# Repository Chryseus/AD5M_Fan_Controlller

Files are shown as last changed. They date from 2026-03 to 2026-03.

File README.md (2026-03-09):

# AD5M Fan Controlller

This is a work in progress fan controller for the Flashforge AD5M / AD5X 3d printer that provides remote fan control over Wifi as well as chamber monitoring.

## Hardware

This is designed for the ESP32 C3 Super Mini but will work with any arduino compatible device that supports Wifi.

BME280 is used for temperature, pressure and humidity sensing.

ENS160 is used for air quality sensing.

Any PWM driver will work for the fans, I've used DRV8871.

Recirculation fan is a 5015 blower, 24V 8500 RPM max.

Exhaust fan is a 4020 24V.

Power is drawn from the built in 24V supply and regulated down to 5V for the ESP32 using a LMR14006Y buck converter (you could use a 7805 instead), the ESP32 3.3V regulator is used to power the sensors.

## 3D Printed Parts

For the recirculation duct [this](https://www.printables.com/model/1243577-flashforge-adventurer-5m-recirculating-air-duct-50) is used for the AD5M, for AD5X users [this](https://www.printables.com/model/1473971-ad5x-internal-circulation-air-filtration-duct-with) or [this](https://www.printables.com/model/1472826-ad5x-recirculation-duct-blower-5015) may work.

For the exhaust duct I have used [this](https://www.printables.com/model/1375541-adventurer-5m-venting-kit-for-the-non-pro-version).

### Roadmap

- [x] Manual fan control

- [x] Sensor display

- [x] Schematic

- [ ] 3D printed mounting parts

- [ ] Automatic mode based on sensor data

**Possible future additions**

- [ ] Data logging / plotting

- [ ] Send data to external server

- [ ] 3D printer communication

- [x] Custom PCB

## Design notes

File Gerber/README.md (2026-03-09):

Intended for JLCPCB

Layers: 2

Material: FR-4

Board Size: 50 x 55mm

Copper: 1oz

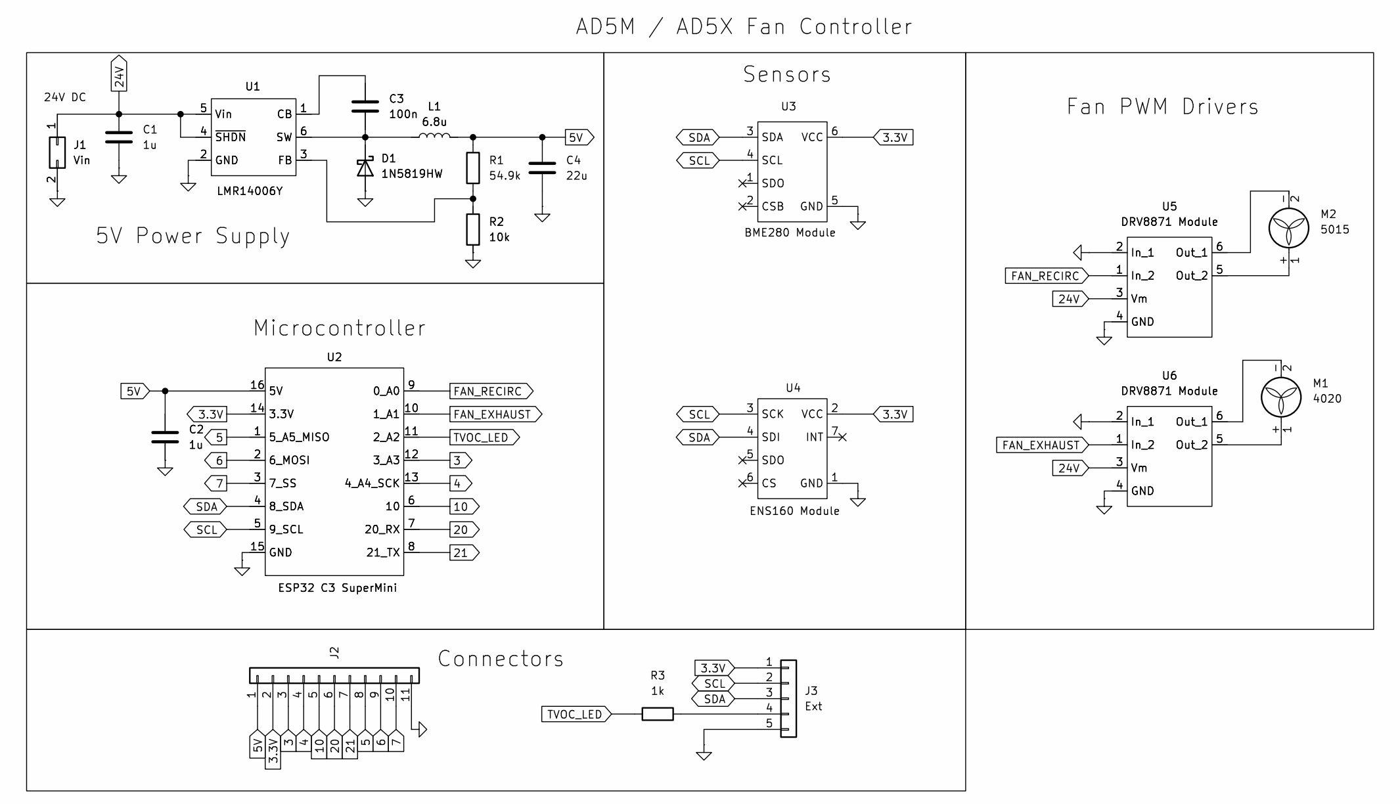
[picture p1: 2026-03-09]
Schematic.png

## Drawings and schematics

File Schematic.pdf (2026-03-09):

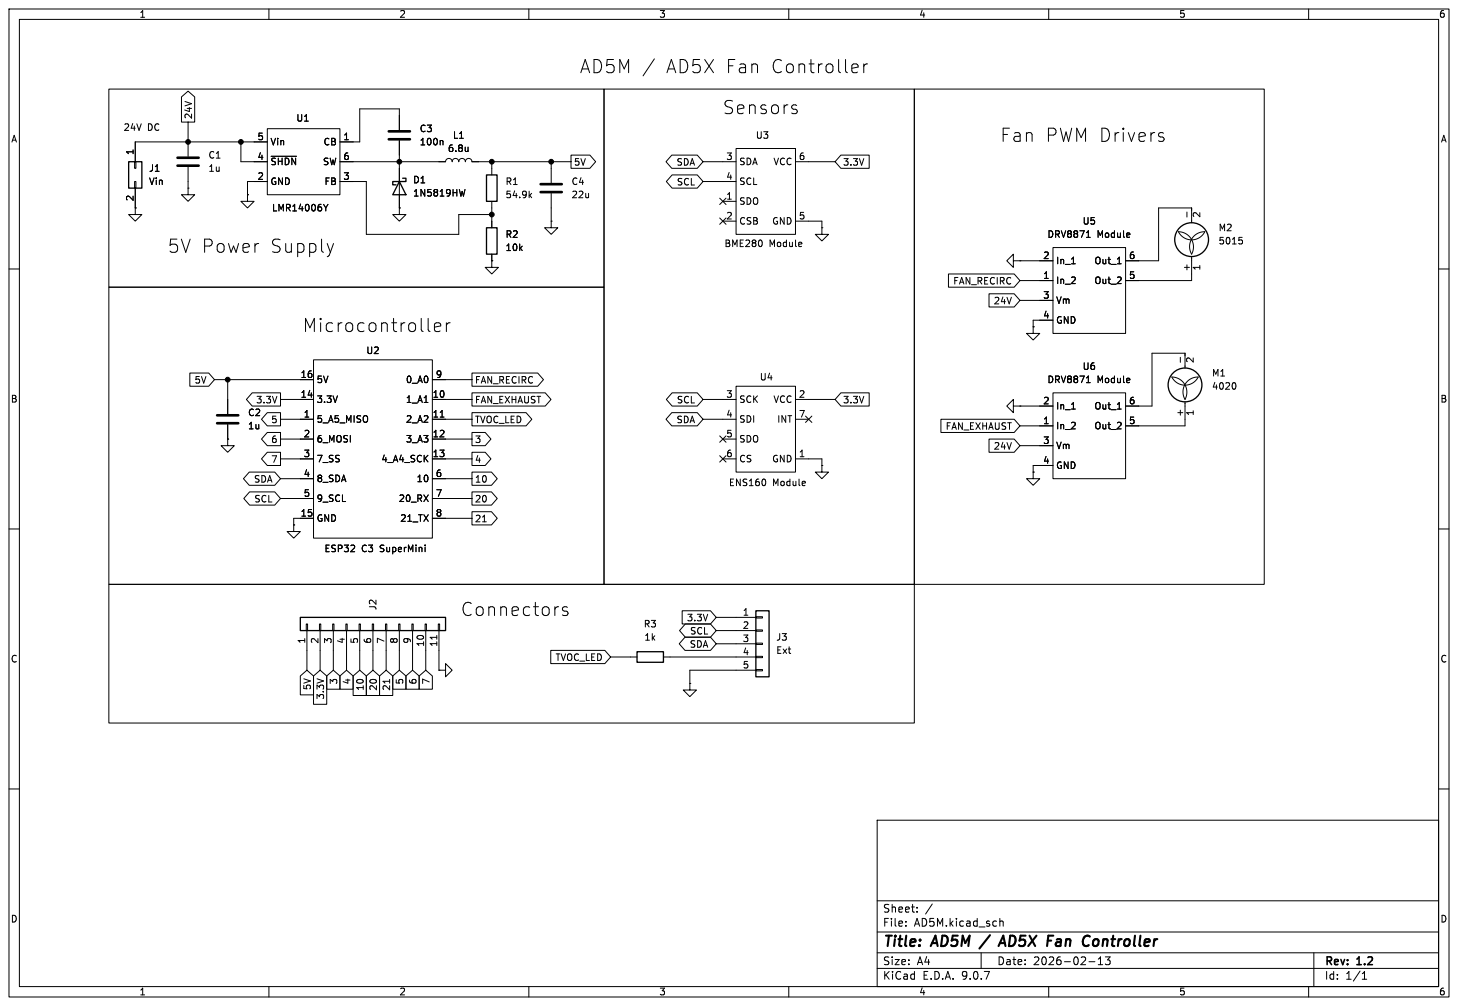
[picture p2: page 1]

Id: 1/1 Title: AD5M / AD5X Fan Controller File: AD5M.kicad_sch Sheet: /

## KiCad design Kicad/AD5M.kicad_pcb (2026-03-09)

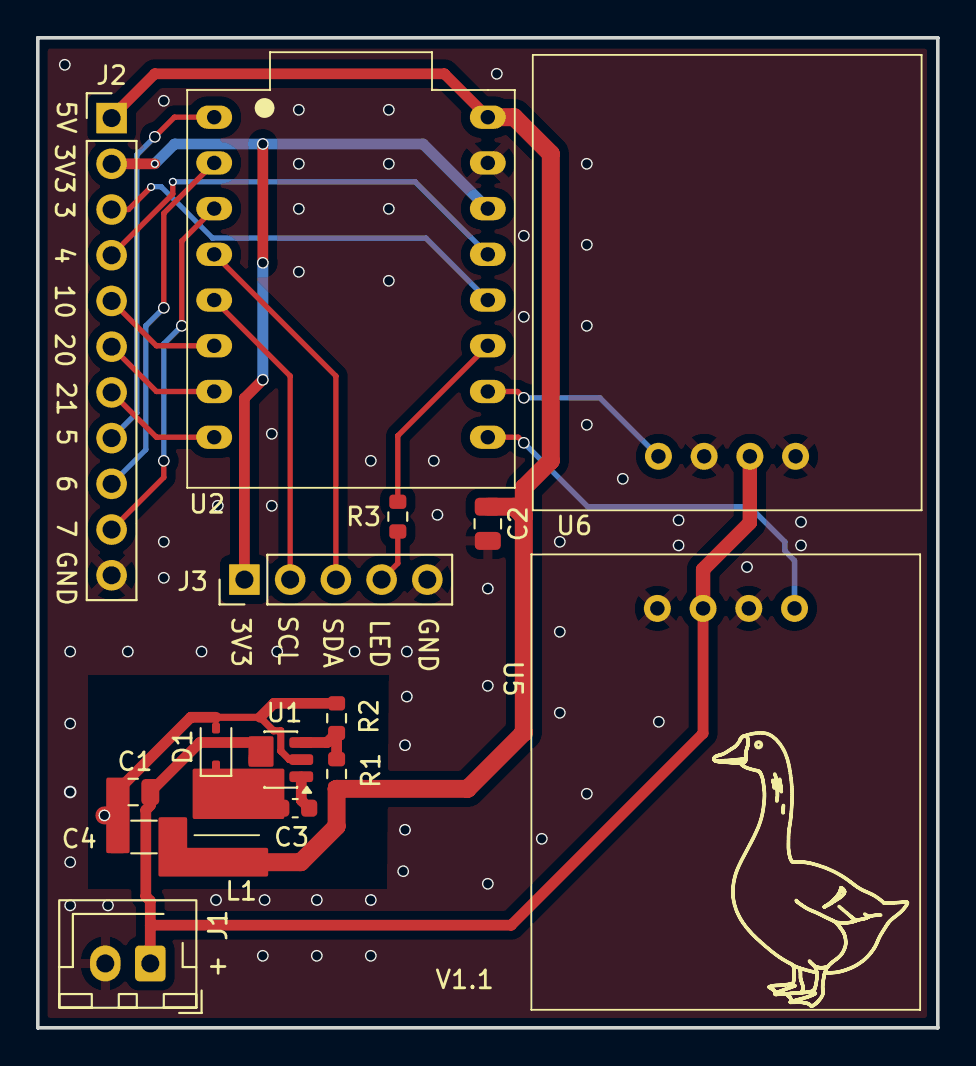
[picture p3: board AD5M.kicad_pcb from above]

Board: 2 copper layers, 50.0 x 55.0 mm, 16 parts (0 on the bottom side), 21 nets.

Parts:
C1, C2: 1u; C_0805_2012Metric
C3: 100n; C_0603_1608Metric
C4: 22u; C_1206_3216Metric
D1: 1N5819HW; D_SOD-323
J1: Vin; JST_XH_B2B-XH-AM_1x02_P2.50mm_Vertical
J2: Conn_01x11; PinHeader_1x11_P2.54mm_Vertical
J3: Ext; PinHeader_1x05_P2.54mm_Vertical
L1: 6.8u; SMNR4030
R1: 54.9k; R_0603_1608Metric
R2: 10k; R_0603_1608Metric
R3: 1k; R_0603_1608Metric
U1: LMR14006Y; TSOT-23-6
U2: ESP32 C3 SuperMini; ESP32_SuperMini_C3
U5, U6: DRV8871 Module

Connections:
3: J2.3, U2.12 (3_A3)
3.3V: J2.2, J3.1, U2.14 (3.3V)
4: J2.4, U2.13 (4_A4_SCK)
5: J2.8, U2.1 (5_A5_MISO)
5V: C2.1, C4.1, J2.1, L1.2, R1.1, U2.16 (5V)
6: J2.9, U2.2 (6_MOSI)
7: J2.10, U2.3 (7_SS)
10: J2.5, U2.6 (10)
20: J2.6, U2.7 (20_RX)
21: J2.7, U2.8 (21_TX)
24V: C1.1, J1.1, U1.4 (~SHDN), U1.5 (Vin), U5.3 (Vm), U6.3 (Vm)
FAN_EXHAUST: U2.10 (1_A1), U6.1 (In_2)
FAN_RECIRC: U2.9 (0_A0), U5.1 (In_2)
GND: C1.2, C2.2, C4.2, D1.2 (A), J1.2, J2.11, J3.5, R2.2, U1.2 (GND), U2.15 (GND), U5.2 (In_1), U5.4 (GND), U6.2 (In_1), U6.4 (GND)
unnamed: C3.2, D1.1 (K), L1.1, U1.6 (SW)
unnamed: J3.4, R3.1
unnamed: C3.1, U1.1 (CB)
unnamed: R1.2, R2.1, U1.3 (FB)
SCL: J3.2, U2.5 (9_SCL)
SDA: J3.3, U2.4 (8_SDA)
TVOC_LED: R3.2, U2.11 (2_A2)

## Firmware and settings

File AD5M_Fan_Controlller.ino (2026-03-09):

/**********************************
*** AD5M Ventilation Controller ***
*** For ESP32 SuperMini C3      ***
***********************************/

#include <WiFi.h> // Arduino WiFi Library
#include <BME280I2C.h> // BME280 Library (Tyler Glenn)
#include <ScioSense_ENS160.h> // ENS160 Adafruit library
#include <Wire.h>
#include <EEPROM.h>
#include "wifi_settings.h" // User WiFi settings

#define NETWORK_PORT 8080
const char* VERSION = "0.2"; // Firmware release version

/**** Pin Layout  ****/
// 8 - I2C SDA
// 9 - I2C SCL
// 0 - PWM Recirculation Fan
// 1 - PWM Exhaust Fan
// 2 - TVOC High LED
const int PIN_SDA = 8;
const int PIN_SCL = 9;
const int PIN_RECIRC = 0;
const int PIN_EXHAUST = 1;
const int PIN_TVOC = 2;

struct VC_Settings {
    int eeprom_saved;
    int mode; // 0 - auto, 1 - manual
    int fan_recirc_enable;
    int fan_exhaust_enable;
    int fan_recirc_pwm;
    int fan_exhaust_pwm;
};
int save_to_eeprom = 0;
VC_Settings vc_settings;
NetworkServer server(NETWORK_PORT);
unsigned long last_wifi_check = 0;
const unsigned long WIFI_CHECK_INTERVAL_MS = 30000;

// Fan Limits
const int fan_recirc_min = 55;
const int fan_exhaust_min = 50;
int fan_recirc_last = 0;
int fan_exhaust_last = 0;


// BME280 Temperature / Humidity / Pressure sensor
bool bme280_detected = false;
bool bmp280_detected = false;
BME280I2C::Settings settings (
    BME280::OSR_X1, //temp
    BME280::OSR_X1, //humid
    BME280::OSR_X4, // pressure
    BME280::Mode_Normal, // Mode
    BME280::StandbyTime_500us, // Standby time
    BME280::Filter_16, // Filter
    BME280::SpiEnable_False,
    BME280I2C::I2CAddr_0x76
);
BME280I2C bme(settings);
float temperature = 0.0; // C
float pressure = 0.0; // hPa
float humidity = 0.0; // RH %

// ENS160 VOC Sensor
bool ens160_detected = false;
ScioSense_ENS160 ens160(ENS160_I2CADDR_1); // Change if needed, 0 = 0x52, 1 = 0x53
int air_AQI = 0; // 1-5
int air_TVOC = 0; // ppb
int air_eCO2 = 0; // ppm

// HTML
String http_header = R"(HTTP/1.1 200 OK
Content-Type: text/html

<!DOCTYPE HTML>
<html>
<head>
	<title>AD5M Ventilation Controller</title>
	<style>
	body { padding: 0; margin: 0; font-family: segoe ui; font-size: 18px;}
	label { margin: 0px 10px; }
  span.safe { color: #1daf1d; }
  span.warn { color: #fdaa28; }
  span.danger { color: #ff1414; }
	#container {
		background-color: #f1f1f1;
		width: 1024px;
		margin: 0px auto;
		padding: 10px; }

	</style>
</head>
<body>
<div id="container">
<h1>AD5M Ventilation Controller</h1>
)";

String http_footer = R"(<br><a href="https://github.com/Chryseus/AD5M_Fan_Controlller">Github</a>
</div>
</body>
</html>

)";

void connect_wifi() {
  while (!WiFi.isConnected()) {
    Serial.print("Connecting to ");
    Serial.println(SSID);
    WiFi.begin(SSID, WPA_KEY);
    delay(10000);
  }

  Serial.println("Connected.");
  Serial.print("Local IP address: ");
  Serial.println(WiFi.localIP());
}

void check_eeprom() {
  EEPROM.get(0, vc_settings);

  if (vc_settings.eeprom_saved != 1)
  {
    Serial.println("Refreshing EEPROM.");
    vc_settings.mode = 0;
    vc_settings.fan_exhaust_enable = 0;
    vc_settings.fan_recirc_enable = 0;
    vc_settings.fan_exhaust_pwm = fan_exhaust_min;
    vc_settings.fan_recirc_pwm = fan_recirc_min;
    vc_settings.eeprom_saved = 1;
    EEPROM.put(0, vc_settings);
    EEPROM.commit();
  }
}

void check_wifi() {
  if (!WiFi.isConnected()) {
    Serial.println("Wifi connection failure, retrying.");
    connect_wifi();
    return;
  }
}

void process_form(String &data, WiFiClient &client) {
  int start = 0;
  while (start < data.length()) {
    int eq = data.indexOf('=', start);
    if (eq < 0)
      break;

    int amp = data.indexOf('&', eq + 1);
    if (amp < 0)
      amp = data.length();

    String key = data.substring(start, eq);
    String value = data.substring(eq + 1, amp);

    if (key == "mode")
      vc_settings.mode = value.toInt();
    else if (key == "recirc")
      vc_settings.fan_recirc_enable = value.toInt();
    else if (key == "recirc_pwm")
      vc_settings.fan_recirc_pwm = value.toInt();
    else if (key == "exhaust")
      vc_settings.fan_exhaust_enable = value.toInt();
    else if (key == "exhaust_pwm")
      vc_settings.fan_exhaust_pwm = value.toInt();
    else if (key == "save")
      save_to_eeprom = value.toInt();

    start = amp + 1;
  }

  Serial.println("Settings updated:");
  Serial.println("Mode: " + String(vc_settings.mode));
  Serial.println("Recirc Fan: " + String(vc_settings.fan_recirc_enable));
  Serial.println("Recirc PWM: " + String(vc_settings.fan_recirc_pwm));
  Serial.println("Exhaust Fan: " + String(vc_settings.fan_exhaust_enable));
  Serial.println("Exhaust PWM: " + String(vc_settings.fan_exhaust_pwm));

  if (save_to_eeprom == 1) {
    Serial.println("Saving settings to EEPROM.");
    vc_settings.eeprom_saved = 1;
    EEPROM.put(0, vc_settings);
    EEPROM.commit();
    save_to_eeprom = 0;
  }

  // Redirect
  client.print("<head>");
  client.print("<meta http-equiv=\"refresh\" content=\"0;url=/\">");
  client.print("</head>");
}

void send_webpage(WiFiClient &client) {
    if(client) {
        while (client.connected()) {
            if (client.available()) {
                String c = client.readStringUntil('\n');
                Serial.println(c);
                client.println(http_header);
                if (c.indexOf('?') > 0) {
                    process_form(c, client);
                }

                if (bme280_detected && !bmp280_detected) {
                    client.println("<h2>BME280 Sensor Data</h2>");
                    client.println("<p>Temperature: " + String(temperature) + " C<br>");
                    client.println("Pressure: " + String(pressure) + " hPa<br>");
                    client.println("Humidity: " + String(humidity) + " %</p>");
                } else if (bme280_detected && bmp280_detected) {
                    client.println("<h2>BMP280 Sensor Data</h2>");
                    client.println("<p>Temperature: " + String(temperature) + " C<br>");
                    client.println("Pressure: " + String(pressure) + " hPa</p>");
                }

                if (ens160_detected) {
                    client.println("<h2>ENS160 Sensor Data</h2>");
                    if (air_TVOC <= 200) {
                        client.println("<p><span class=safe>TVOC: " + String(air_TVOC) + " ppb</span><br>");
                    } else if (air_TVOC > 200 && air_TVOC < 600) {
                        client.println("<p><span class=warn>TVOC: " + String(air_TVOC) + " ppb</span><br>");
                    } else {
                        client.println("<p><span class=danger>TVOC: " + String(air_TVOC) + " ppb</span><br>");
                    }

                    if (air_eCO2 <= 800) {
                        client.println("<span class=safe>eCO2: " + String(air_eCO2) + " ppm</span><br>");
                    } else if (air_eCO2 > 800 && air_eCO2 < 1500) {
                        client.println("<span class=warn>eCO2: " + String(air_eCO2) + " ppm</span><br>");
                    } else {
                        client.println("<span class=danger>eCO2: " + String(air_eCO2) + " ppm</span><br>");
                    }

                    if (air_AQI <= 2 ) {
                        client.println("<span class=safe>AQI: " + String(air_AQI) + "</span></p>");
                    } else if (air_AQI > 2 && air_AQI <= 4) {
                        client.println("<span class=warn>AQI: " + String(air_AQI) + "</span></p>");
                    } else {
                        client.println("<span class=danger>AQI: " + String(air_AQI) + "</span></p>");
                    }
                }

                client.println("<h2>Settings</h2><form method=\"get\" action=\"\"><fieldset><legend>Mode</legend>");
                if(vc_settings.mode == 0) {
                    client.println("<label for=\"auto\">Automatic</label><input type=\"radio\" id=\"auto\" name=\"mode\" value=\"1\" checked><label for=\"manual\">Manual Override</label><input type=\"radio\" id=\"manual\" name=\"mode\" value=\"0\">");
                } else {
                    client.println("<label for=\"auto\">Automatic</label><input type=\"radio\" id=\"auto\" name=\"mode\" value=\"1\"><label for=\"manual\">Manual Override</label><input type=\"radio\" id=\"manual\" name=\"mode\" value=\"0\" checked>");
                }
                client.println("</fieldset><br><fieldset><legend>Recirculation Fan</legend>");

                if (vc_settings.fan_recirc_enable == 1) {
                    client.println("<label for=\"recirc_enable\">Enable</label><input type=\"radio\" id=\"recirc_enable\" name=\"recirc\" value=\"1\" checked>");
                    client.println("<label for=\"recirc_disable\">Disable</label><input type=\"radio\" id=\"recirc_disable\" name=\"recirc\" value=\"0\"><br>");
                } else {
                    client.println("<label for=\"recirc_enable\">Enable</label><input type=\"radio\" id=\"recirc_enable\" name=\"recirc\" value=\"1\">");
                    client.println("<label for=\"recirc_disable\">Disable</label><input type=\"radio\" id=\"recirc_disable\" name=\"recirc\" value=\"0\" checked><br>");
                }
                client.println("<label for=\"recirc_pwm\">Speed</label><input type=\"number\" id=\"recirc_pwm\" name=\"recirc_pwm\" value=\"" + String(vc_settings.fan_recirc_pwm) + "\" min=\"" + fan_recirc_min + "\" max=\"100\"> %");
                client.println("</fieldset><br><fieldset><legend>Exhaust Fan</legend>");

                if(vc_settings.fan_exhaust_enable == 1) {
                    client.println("<label for=\"exhaust_enable\">Enable</label><input type=\"radio\" id=\"exhaust_enable\" name=\"exhaust\" value=\"1\" checked>");
                    client.println("<label for=\"exhaust_disable\">Disable</label><input type=\"radio\" id=\"exhaust_disable\" name=\"exhaust\" value=\"0\"><br>");
                } else {
                    client.println("<label for=\"exhaust_enable\">Enable</label><input type=\"radio\" id=\"exhaust_enable\" name=\"exhaust\" value=\"1\">");
                    client.println("<label for=\"exhaust_disable\">Disable</label><input type=\"radio\" id=\"exhaust_disable\" name=\"exhaust\" value=\"0\" checked><br>");
                }
                client.println("<label for=\"exhaust_pwm\">Speed</label><input type=\"number\" id=\"exhaust_pwm\" name=\"exhaust_pwm\" value=\"" + String(vc_settings.fan_exhaust_pwm) + "\" min=\"" + fan_exhaust_min + "\" max=\"100\"> %");
                client.println("</fieldset><br><fieldset><legend>Misc</legend>");

                client.println("<label for=\"save\">Save settings to EEPROM</label><input type=\"checkbox\" id=\"save\" name=\"save\" value=\"1\">");
                client.println("</fieldset><br><input type=\"Submit\" value=\"Apply Settings\"></form>");

                client.println(http_footer);
                break;

            }
        }
        client.stop();
    }
}

void setup() {
  Serial.begin(9600);
  Serial.println("AD5M fan controller and monitoring.");
  Serial.print("Version: ");
  Serial.println(VERSION);
  pinMode(PIN_RECIRC, OUTPUT);
  pinMode(PIN_RECIRC, OUTPUT);
  pinMode(PIN_TVOC, OUTPUT);
  analogWriteFrequency(0, 30e3);
  analogWriteFrequency(1, 30e3);
  Wire.begin();
  EEPROM.begin(sizeof(vc_settings));
check_eeprom();

  if (!bme.begin()) {
    Serial.println("BME280 not found, some features may not be available.");
  } else {
    bme280_detected = true;
    if (bme.chipModel() == BME280::ChipModel_BMP280) {
      Serial.println(
          "BMP280 detected, humidity reading will not be available.");
      bmp280_detected = true;
    }
  }

  ens160.begin();
  if (!ens160.available()) {
    Serial.println(
        "ENS160 is not available, some features may not be available.");
  } else {
    ens160.setMode(ENS160_OPMODE_STD);
    ens160_detected = true;
  }

  connect_wifi();
  server.setTimeout(120);
  server.begin();
}

void loop() {
  unsigned long now_ms = millis();
  if (now_ms - last_wifi_check >= WIFI_CHECK_INTERVAL_MS) {
    check_wifi();
    last_wifi_check = now_ms;
  }

  if (bme280_detected && !bmp280_detected) {
    bme.read(pressure, temperature, humidity);
  } else if (bme280_detected && bmp280_detected) {
    temperature = bme.temp();
    pressure = bme.pres();
  }

  if (ens160_detected) {
    ens160.measure(false); // don't block
    air_AQI = ens160.getAQI();
    air_eCO2 = ens160.geteCO2();
    air_TVOC = ens160.getTVOC();
  }

  WiFiClient client = server.available();
  send_webpage(client);

  // Fan Control
  if (vc_settings.fan_recirc_enable > 0) {
    float output = (vc_settings.fan_recirc_pwm / 100.0f) * 255.0f;
    int ioutput = (int)output;
    if (fan_recirc_last == 0) {
      fan_recirc_last = vc_settings.fan_recirc_pwm;
      analogWrite(PIN_RECIRC, 255);
      delay(500);
    }
    analogWrite(PIN_RECIRC, ioutput);
  } else {
    analogWrite(PIN_RECIRC, 0);
    fan_recirc_last = 0;
  }

  if (vc_settings.fan_exhaust_enable > 0) {
    float output2 = (vc_settings.fan_exhaust_pwm / 100.0f) * 255.0f;
    int ioutput2 = (int)output2;
    if (fan_exhaust_last == 0) {
      fan_exhaust_last = vc_settings.fan_exhaust_pwm;
      analogWrite(PIN_EXHAUST, 255);
      delay(500);
    }
    analogWrite(PIN_EXHAUST, ioutput2);
  } else {
    analogWrite(PIN_EXHAUST, 0);
    fan_exhaust_last = 0;
  }

  // TVOC LED
  if (air_TVOC > 600) {
    digitalWrite(PIN_TVOC, HIGH);
  } else {
    digitalWrite(PIN_TVOC, LOW);
  }
}

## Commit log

2026-02-12 Made sensors optional Added support for BMP280 Added github link to interface
2026-02-13 Added schematic.
2026-02-16 Fixed exhaust fan output Increased PWM frequency to 30kHz Added logic to ensure fan startup Added TVOC High LED support Updated schematic
    [AD5M_Fan_Controlller.ino]
2026-02-28 Update Schematic, Add PCB gerbers.
    [AD5M-B_Cu.gbl, AD5M-B_Mask.gbs, AD5M-B_Paste.gbp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]
2026-02-28 Add KiCad files.
    [AD5M.kicad_pcb, AD5M.kicad_sch]
2026-03-09 Fixed ESP32 footprint & symbol Updated KiCad files Updated gerbers to board version 1.1
    [AD5M-B_Cu.gbl, AD5M-B_Mask.gbs, AD5M-B_Paste.gbp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]
2026-03-09 Update schematic
